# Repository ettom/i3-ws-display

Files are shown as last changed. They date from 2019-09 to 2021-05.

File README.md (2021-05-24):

# i3-ws-display
Display active [i3](https://i3wm.org/) workspaces on a 7-segment display

A set of programs and configuration files for displaying i3 workspaces on a display
controlled by an Arduino Nano.

## Background
I started using a secondary monitor and didn't want to waste screen real estate for
a status bar on it. However, peeking at the other monitor to see which workspaces
are active felt awkward. This led me to create this project. The end
result is a 4-digit 7-segment display that shows the active workspaces, mounted on
top of my external monitor. It also shows if a workspace is visible by lighting up
the dot after the corresponding workspace number.

There is no real reason to be limited to a 4-digit display, or in fact - a 7-segment
display. I have workspaces 4-7 mapped to my external display. This setup works quite
well for me.

## Hardware setup
#### You'll need:
* Arduino Nano. Technically any Arduino should work, but then you'll have to rewrite
 the pin mappings/use a library for the 7-segment display.
* 7-segment display module. Mine is labelled HS420561K-32. It's a 4-digit
 common-cathode unit. It's important that there is a dot after every digit so you
  can indicate the currently visible workspace.
* Four 220-ohm resistors and wires to connect it all up

#### Setup
Connect the display to your Arduino. If you want the numbers on the display to align
left, change the `align_to_right` symbol to `false` in `uc/src/main.cpp`. Then flash
the file to your Arduino using [PlatformIO](https://platformio.org/). To do that, run
the following commands in the root directory of the project:
```
cd uc
pio run -t upload
```

Wiring for a common-cathode display with the following pin arrangement (according
to the [typical segment identification](https://commons.wikimedia.org/wiki/File:7_Segment_Display_with_Labeled_Segments.svg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)):<br>
**Top row** - 1, a, f, 2, 3, b <br>
**Bottom row** - e, d, DP, c, g, 4

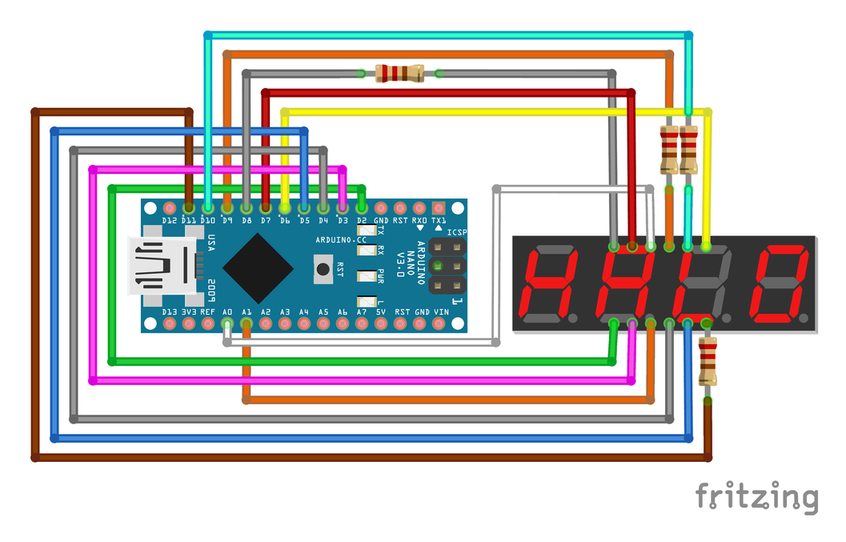
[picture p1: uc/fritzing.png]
Fritzing schematic


## Software setup
Arch Linux users can use the provided `PKGBUILD`.

### Dependencies
A compiler with C++17 support ([clang-5+](http://llvm.org/releases/download.html),
[gcc-7+](https://gcc.gnu.org/releases.html)), [cmake 3.11+](https://cmake.org/download/), [git](https://git-scm.com/downloads)
```
pkgconf
libserial
jsoncpp
sigc++
```

This project also uses the [i3ipcpp](https://github.com/drmgc/i3ipcpp) library
which is pulled and built automatically by cmake.

### Building
Run the following commands:
```
cd linux
mkdir build && cd build
cmake ..
make
sudo make install
```

### Configuration
Run `ws-display --help` to see available configuration options.

You'll probably want to write an udev rule for the Arduino. Otherwise it might not
always get bound to the same `/dev` node.<br>
Unfortunately the Arduino Nano does not have a serial id, so it's difficult to write
an udev rule for it. I found that the easiest way was to tie it to a USB
hub port. This works as long as the Arduino is always plugged into the same USB
port.<br>
I won't go into writing udev rules here, see the `97-ws-display.rules` file
for an example. I found [this](https://unix.stackexchange.com/a/326708) post helpful.

If the Arduino will always be connected to your machine you could (and should) just
start `ws-display` from your i3 config.

I have a laptop and a docking station to which the Arduino is connected to so I'm
using a systemd user service for starting and stopping `ws-display`. The systemd user
service starts `ws-display` as soon as the Arduino becomes available. The service
also depends on a custom `i3.target` which gets started by i3:

`exec_always --no-startup-id systemctl --user restart i3.target`

I also put `systemctl --user stop i3.target` in a script that runs when i3 exits. See the
`systemd/ws-display.service` and `systemd/i3.target` files.

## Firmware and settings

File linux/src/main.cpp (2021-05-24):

#include "serial-commands.h"

#include <CLI/CLI.hpp>
#include <i3ipc++/ipc.hpp>
#include <libserial/SerialPort.h>

#include <algorithm>
#include <iostream>
#include <stdexcept>
#include <string>
#include <unistd.h>

struct Config {
	std::string target_serial_port;
	std::string output;
	size_t display_length {4};
	unsigned int startup_delay_ms {1500};
	bool blink_on_urgent = false;
};

struct State {
	std::string workspaces;
	std::string visible;
	std::string urgent;
};

using namespace LibSerial;

void send_to_arduino(const State& state, SerialPort& serial_port)
{
	const std::string payload {state.workspaces + serial_commands::workspaces_sent + state.visible
				   + serial_commands::visible_sent + state.urgent + serial_commands::urgent_sent};

	serial_port.Write(payload);
	serial_port.DrainWriteBuffer();
}

void initialize_serial(SerialPort& serial_port)
{
	serial_port.SetBaudRate(BaudRate::BAUD_19200);
	serial_port.SetCharacterSize(CharacterSize::CHAR_SIZE_8);
	serial_port.SetFlowControl(FlowControl::FLOW_CONTROL_NONE);
	serial_port.SetParity(Parity::PARITY_NONE);
	serial_port.SetStopBits(StopBits::STOP_BITS_1);
}

void prepare_workspaces(State& state, const Config& config)
{
	if (state.workspaces.empty()) {
		return;
	}

	auto ensure_visible_displayed = [&]() {
		std::string tmp = state.visible;
		for (auto c : state.workspaces) {
			if (tmp.length() == config.display_length) {
				break;
			}
			if (tmp.find(c) == std::string::npos) {
				tmp += c;
			}
		}
		return tmp;
	};

	if (state.workspaces.length() > config.display_length) {
		state.workspaces = ensure_visible_displayed();
	}

	std::sort(state.workspaces.begin(), state.workspaces.end());

	if (state.workspaces.at(0) == '0') {
		state.workspaces.erase(0, 1);
		state.workspaces.insert(state.workspaces.length(), "0");
	}
}

State find_workspaces(const Config& config, const i3ipc::connection& conn)
{
	static auto prepare_workspace_name = [](const std::string& workspace_name) {
		const size_t n {workspace_name.find_first_of("0123456789")};
		if (n == std::string::npos) {
			throw std::logic_error("Workspace names must contain at least one numeric character!");
		}

		const size_t m {workspace_name.find_first_not_of("0123456789", n)};

		const std::string result = workspace_name.substr(n, (m == std::string::npos) ? m : m - n);
		return (result == "10") ? '0' : result.at(0);
	};

	State state {};
	for (const auto& workspace : conn.get_workspaces()) {
		if (!config.output.empty() && workspace->output != config.output) {
			continue;
		}

		const char workspace_number = prepare_workspace_name(workspace->name);
		if (workspace->visible) {
			state.visible += workspace_number;
		}

		if (config.blink_on_urgent && workspace->urgent) {
			state.urgent += workspace_number;
		}

		state.workspaces += workspace_number;
	}

	return state;
}

void update_display(const Config& config, const i3ipc::connection& conn, SerialPort& serial_port)
{
	State state {find_workspaces(config, conn)};
	prepare_workspaces(state, config);
	send_to_arduino(state, serial_port);
}

int main(int argc, char* argv[])
{
	CLI::App app {"Display active i3 workspaces on a 7-segment display"};
	app.option_defaults()->always_capture_default();

	Config config;

	app.add_option("-o,--output", config.output, "Show workspaces only for this output");

	app.add_option("-l,--display-length", config.display_length, "Number of digits on your 7-segment display")
		->check(CLI::PositiveNumber);

	app.add_option("-p,--serial_port", config.target_serial_port, "Serial port your Arduino is connected to")
		->check(CLI::ExistingFile)
		->required();

	app.add_option("-d,--startup-delay", config.startup_delay_ms,
		       "Milliseconds to wait for the Arduino to restart on initial connection")
		->check(CLI::PositiveNumber);

	app.add_flag("-b,--blink-urgent", config.blink_on_urgent,
		     "Blink the dot if an application sets an urgent flag on a workspace");

	CLI11_PARSE(app, argc, argv);

	SerialPort serial_port;

	try {
		serial_port.Open(config.target_serial_port);
		initialize_serial(serial_port);
	} catch (const OpenFailed&) {
		std::cerr << "The serial port " << config.target_serial_port << " did not open correctly." << std::endl;
		return EXIT_FAILURE;
	}

	// wait for a bit for the Arduino to restart
	usleep(config.startup_delay_ms * 1000);

	try {
		i3ipc::connection conn;

		conn.signal_workspace_event.connect([&](__attribute__((unused)) const i3ipc::workspace_event_t&) {
			update_display(config, conn, serial_port);
		});
		conn.subscribe(i3ipc::ET_WORKSPACE);

		update_display(config, conn, serial_port);
		for (;;) {
			conn.handle_event();
		}
	} catch (const std::runtime_error& e) {
		std::cerr << e.what() << std::endl;
		return EXIT_FAILURE;
	}

	return EXIT_SUCCESS;
}

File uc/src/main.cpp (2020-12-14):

#include "serial-commands.h"

#include <Arduino.h>

constexpr bool align_to_right = true;
constexpr uint8_t display_length = 4;
constexpr uint16_t urgent_blink_interval_ms = 700;

enum segment {
	seg_A = 0x80,
	seg_B = 0x40,
	seg_G = 0x20,
	seg_C = 0x10,
	seg_D = 0x08,
	seg_E = 0x04,
	seg_F = 0x01,
	seg_DP = 0x02
};

enum common { com_1 = 0xfe, com_2 = 0xfd, com_3 = 0xfb, com_4 = 0xf7 };

const uint8_t decimals[10] = {seg_A | seg_B | seg_C | seg_D | seg_E | seg_F,
			      seg_B | seg_C,
			      seg_A | seg_B | seg_G | seg_E | seg_D,
			      seg_A | seg_B | seg_G | seg_C | seg_D,
			      seg_B | seg_C | seg_F | seg_G,
			      seg_A | seg_F | seg_G | seg_C | seg_D,
			      seg_A | seg_C | seg_D | seg_E | seg_F | seg_G,
			      seg_A | seg_B | seg_C,
			      seg_A | seg_B | seg_C | seg_D | seg_E | seg_F | seg_G,
			      seg_A | seg_B | seg_C | seg_D | seg_F | seg_G};

const uint8_t coms[display_length] = {com_1, com_2, com_3, com_4};

const uint8_t refresh_interval = 100;
unsigned long start_millis = 0, current_millis = 0, urgent_millis = 0;

String rx_buf = "";
String to_print = "8888", visible_workspaces = "8888", urgent_workspaces = "";

bool urgent_on = false;

void all_off()
{
	PORTB = PORTD = PORTC = 0;
}

void light_segments(int number)
{
	PORTD = decimals[number];
	if ((decimals[number] & seg_F) == seg_F) {
		PORTC |= seg_F;
	} else {
		PORTC &= ~seg_F;
	}
}

void light_index(int index)
{
	PORTB = coms[index];
}

void light_dot(int index, int digit)
{
	static auto contains = [](const String& s, int to_search) {
		for (size_t i = 0; i < s.length(); ++i) {
			if (s[i] - '0' == to_search) {
				return true;
			}
		}
		return false;
	};

	if (contains(visible_workspaces, digit) || (urgent_on && contains(urgent_workspaces, digit))) {
		PORTC |= seg_DP;
	} else {
		PORTC &= ~seg_DP;
	}
}

void print_digit(int index, int digit)
{
	light_dot(index, digit);
	light_segments(digit);
	light_index(index);
	delay(2);
}

void print_number(const String& number)
{
	while (current_millis - start_millis < refresh_interval) {
		current_millis = millis();

		int position_shift = 0;
		if (align_to_right) {
			position_shift = number.length() - (display_length);
			position_shift = abs(position_shift);
		}

		for (size_t i = 0; i < number.length(); ++i) {
			print_digit(i + position_shift, number[i] - '0');
		}
	}

	start_millis = current_millis;
}

bool is_valid_cmd(char c)
{
	return isDigit(c) || (c == serial_commands::workspaces_sent) || (c == serial_commands::visible_sent)
	       || (c == serial_commands::urgent_sent);
}

void setup() // {{{1
{
	/*
	     A
	  |-----|
	F |  G  | B
	  |-----|
	E |     | C
	  |-----|
	     D    [•]

	   */

	// declare outputs
	// segment control
	//-------ABGCDE--
	DDRD = 0b11111100; // pins D7-D2
	//-------------•F
	DDRC = 0b00000011; // pins A1-A0

	// digit control
	//-----------1234
	DDRB = 0b00001111; // pins D11-D8

	Serial.begin(19200);
} // 1}}}

void loop()
{
	while (Serial.available() > 0) {
		char in_char = Serial.read();
		if (!is_valid_cmd(in_char)) {
			continue;
		}

		switch (in_char) {
		case serial_commands::workspaces_sent:
			to_print = rx_buf;
			rx_buf = "";
			break;
		case serial_commands::visible_sent:
			visible_workspaces = rx_buf;
			rx_buf = "";
			break;
		case serial_commands::urgent_sent:
			urgent_workspaces = rx_buf;
			rx_buf = "";
			break;
		default:
			rx_buf += in_char;
		}
	}

	if (to_print.length() == 0) {
		all_off();
	} else {
		print_number(to_print);
	}

	if (millis() - urgent_millis > urgent_blink_interval_ms) {
		urgent_millis = millis();
		urgent_on = !urgent_on;
	}
}
// vim:fdm=marker:fmr={{{,}}}

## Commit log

2019-09-28 Fix checking for focused workspace
    Remove the meaningless check. Instead check for the placeholder.
    This is necessary because find() will return npos if it doesn't find a
    match and thus focused_workspace_not_displayed will evaluate to true
    even if a focused workspace wasn't found.
    [main.cpp]
2019-09-28 Print newline after error message
    [main.cpp]
2019-09-28 Remove misleading instruction about DISPLAY_LENGTH
    Using a display that doesn't have 4 digits will require rewriting some
    of the Arduino program anyway - changing the DISPLAY_LENGTH variable is
    not enough.
2019-09-29 Handle exceptions that may occur on startup
    Move sorting of workspace string out of find_workspaces.
    Fix some style issues, improve readability.
    [main.cpp]
2019-09-29 Fix out of range error when workspace string empty
    [main.cpp]
2019-11-12 Include filename in error message
    [main.cpp]
2019-11-12 Pass error description to exception
    [main.cpp]
2019-11-12 Remove unnecessary print
2019-11-12 Replace focused with visible
    [main.cpp]
2019-11-12 Print the serial port name with error message
    [main.cpp]
2020-02-06 Use hyphens instead of underscores
    [ws-display.fzz]
2020-02-17 Refactor Arduino code
2020-02-19 Use shared serial commands
    [ws-display.fzz]
2020-02-19 Fix minor semantic issues
    [main.cpp]
2020-02-19 Throw if workspace name doesn't contain a number
    Throw logic_error if no numeric character found
    [main.cpp]
2020-03-02 Zero-initialize millis
2020-04-18 Add .clang-tidy, fix warnings
    [main.cpp]
2020-06-02 Catch runtime_error in main
    This is necessary to prevent the program dumping core if i3 exits or the
    Arduino becomes unavailable for some reason.
    [main.cpp]
2020-09-21 Add support for platformio
    [ws-display.fzz]
2020-10-11 Fix workspaces not getting sorted
    [main.cpp]
